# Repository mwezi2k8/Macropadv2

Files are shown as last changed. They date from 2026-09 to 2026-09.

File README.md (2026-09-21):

# 12-key macropad 

#what is it?
this is a custom 12-key mechanical macropad i designed in kicad from scratch. it runs on a seeed studio xiao rp2040 board instead of a bulky standard dev board, which keeps the whole thing compact and cheap. it has a 4x3 switch matrix with anti-ghosting diodes, a clickable rotary encoder knob, and a 4-pin header on top for a small i2c oled display.



# why make this?
i use a 60% keyboard daily, and while it looks clean and saves desk space, losing dedicated arrow keys, media buttons, and numpad shortcuts is honestly a pain. memorizing three-key layer combos while working or gaming gets frustrating fast. 

i wanted a standalone pad with dedicated hardware buttons for stuff like discord mutes, copy-pasting, app switching, and terminal shortcuts. plus, having a physical rotary dial to control volume or scrub timelines is way more satisfying than pressing function keys.



#how does it work?
- the key matrix:* the 12 switches are wired in a 4-column by 3-row grid connected directly to the xiao gpio pins. the micro-controller quickly scans through the rows and columns to check if a circuit is closed
- diodes* each switch has its own 1n4148 diode wired in series[cite: 3]. this stops back-powering across rows so you can press multiple keys at the same time without triggering phantom ghost clicks.
- rotary encoder:* the ec11 encoder pulses signals across two data pins whenever you turn it, letting the code figure out both direction and speed for scrolling or volume adjustments. the center shaft also clicks straight down, working as a 13th input switch
- oled screen:* hooked up to 5v, ground, sda, and scl pins. it talks over the i2c bus to show what profile or layer you are on, or display real-time stats like click counters.



#hardware & pcb specs
- controller:* seeed studio xiao rp2040
- keys:* 12 push switches arranged with standard 19.05 mm (1u) spacing so normal mechanical keycaps fit properly
- diodes:* 12x 1n4148 through-hole diodes placed next to each switch
- encoder:* ec11 rotary encoder with integrated push switch
- display connector:* 4-pin 2.54mm header for 0.96" i2c oled
- board size:*85.91 mm x 84.00 mm (2-layer pcb)



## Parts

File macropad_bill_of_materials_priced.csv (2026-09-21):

Item | Reference | Quantity | Component / Value | Footprint | Description | Unit Price (USD) | Total Price (USD)
1 | SW1 - SW12 | 12 | Cherry MX Compatible Switch | Button_Switch_Keyboard:SW_Cherry_MX_1.00u_PCB | Mechanical keyboard switch (Gateron / Outemu / Cherry) | 0.25 | 3.0
2 | D1 - D12 | 12 | 1N4148 Diode | Diode_THT:D_DO-35_SOD27_P7.62mm_Horizontal | High-speed switching diode (DO-35) | 0.03 | 0.36
3 | SW13 (SCROLL1) | 1 | EC11 Rotary Encoder | Rotary_Encoder:RotaryEncoder_Alps_EC11E-Switch_Vertical_H20mm | Rotary encoder with integrated push switch | 1.1 | 1.1
4 | U1 | 1 | Seeed Studio XIAO RP2040 | Seeed_XIAO:Seeed-XIAO / DIP-14_W15.24mm | Dual-core ARM Cortex-M0+ MCU module | 5.4 | 5.4
5 | J1 | 1 | Conn_01x04_Pin | Connector_PinHeader_2.54mm:PinHeader_1x04_P2.54mm_Vertical | 1x4 pin male header, 2.54mm pitch | 0.15 | 0.15
6 | DISP1 (External) | 1 | 0.96" I2C OLED Display | PinHeader_1x04_P2.54mm (Header) | 128x64 SSD1306 monochrome OLED module | 2.5 | 2.5
7 | PCB | 1 | Custom 2-Layer PCB | 85.91mm x 84.00mm | FR-4 2-Layer custom board (est. per board from 5-pack) | 1.5 | 1.5
8 | MISC1 | 12 | 1u Keycaps | Standard MX Stem | Standard 1u profile keycaps | 0.2 | 2.4
9 | MISC2 | 1 | Rotary Encoder Knob | 6mm Shaft | Aluminum / plastic knob cap for 6mm shaft | 0.75 | 0.75

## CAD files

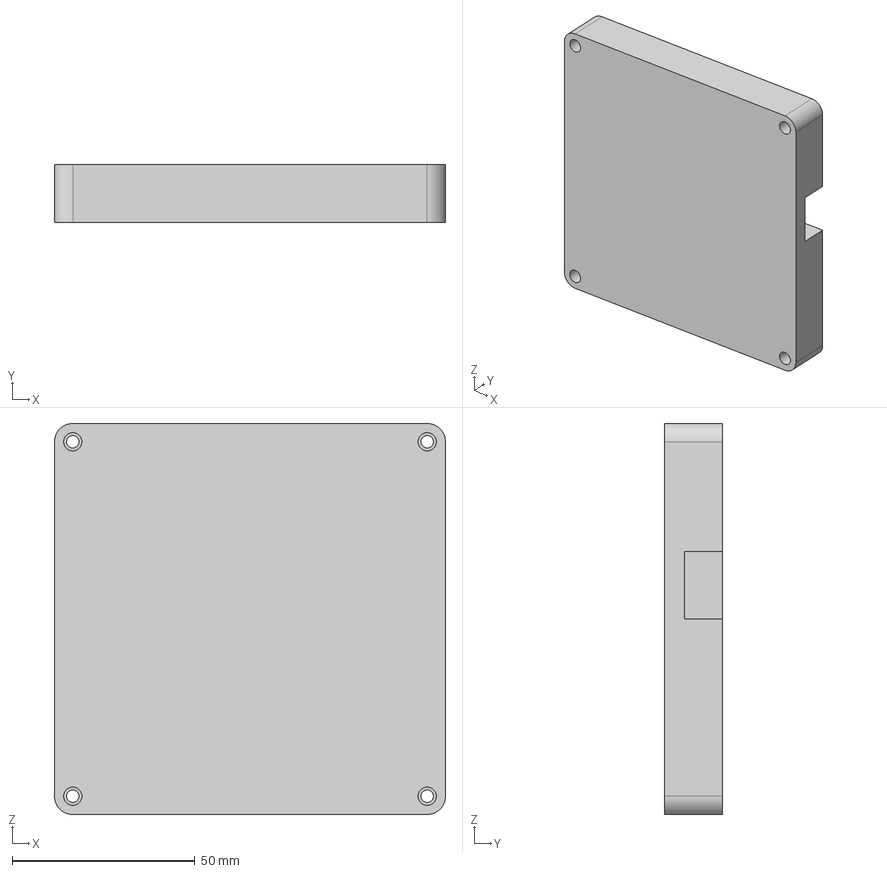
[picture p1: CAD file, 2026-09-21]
Case Bottom.step
106.9 x 15.9 x 106.9 mm

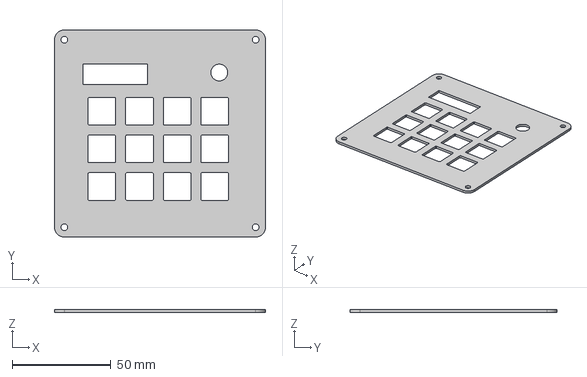
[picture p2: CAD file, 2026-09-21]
Case top.step
106.9 x 105.0 x 1.50 mm

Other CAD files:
Final Assembly Macropad.f3z

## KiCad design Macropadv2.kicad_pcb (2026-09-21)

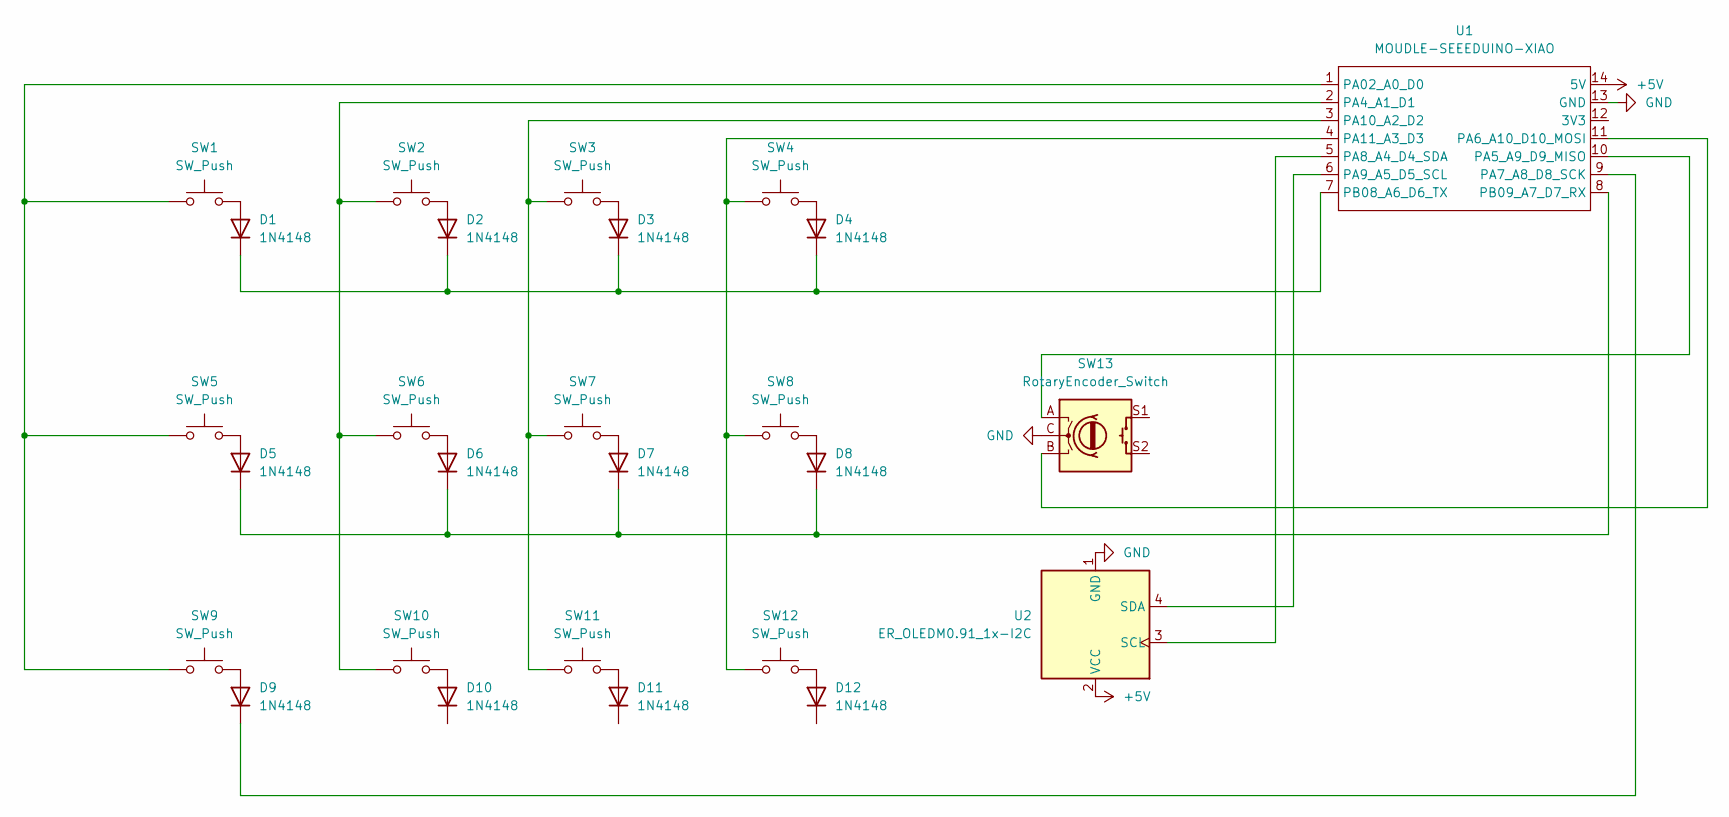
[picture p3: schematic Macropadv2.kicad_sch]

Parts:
D1, D2, D3, D4, D5, D6, D7, D8, D9, D10, D11, D12: 1N4148; D_DO-35_SOD27_P7.62mm_Horizontal
SW1, SW2, SW3, SW4, SW5, SW6, SW7, SW8, SW9, SW10, SW11, SW12: SW_Push; SW_NKK_GW12LJP
SW13: RotaryEncoder_Switch; RotaryEncoder_Alps_EC11E-Switch_Vertical_H20mm
U1: MOUDLE-SEEEDUINO-XIAO; XIAO-Generic-Hybrid-14P-2.54-21X17.8MM
U2: ER_OLEDM0.91_1x-I2C

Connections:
+5V: U1.14 (5V), U2.2 (VCC)
GND: SW13.C, U1.13 (GND), U2.1 (GND)
unnamed: D1.2 (A), SW1.2
unnamed: D1.1 (K), D2.1 (K), D3.1 (K), D4.1 (K), U1.7 (PB08_A6_D6_TX)
unnamed: D2.2 (A), SW2.2
unnamed: D3.2 (A), SW3.2
unnamed: D4.2 (A), SW4.2
unnamed: D5.2 (A), SW5.2
unnamed: D5.1 (K), D6.1 (K), D7.1 (K), D8.1 (K), U1.8 (PB09_A7_D7_RX)
unnamed: D6.2 (A), SW6.2
unnamed: D7.2 (A), SW7.2
unnamed: D8.2 (A), SW8.2
unnamed: D9.2 (A), SW9.2
unnamed: D9.1 (K), U1.9 (PA7_A8_D8_SCK)
unnamed: D10.2 (A_2), SW10.2
unnamed: D11.2 (A_2), SW11.2
unnamed: D12.2 (A_2), SW12.2
unnamed: SW1.1, SW5.1, SW9.1, U1.1 (PA02_A0_D0)
unnamed: SW2.1, SW6.1, SW10.1, U1.2 (PA4_A1_D1)
unnamed: SW13.A, U1.10 (PA5_A9_D9_MISO)
unnamed: SW13.B, U1.11 (PA6_A10_D10_MOSI)
unnamed: U1.5 (PA8_A4_D4_SDA), U2.3 (SCL)
unnamed: U1.6 (PA9_A5_D5_SCL), U2.4 (SDA)
unnamed: SW3.1, SW7.1, SW11.1, U1.3 (PA10_A2_D2)
unnamed: SW4.1, SW8.1, SW12.1, U1.4 (PA11_A3_D3)

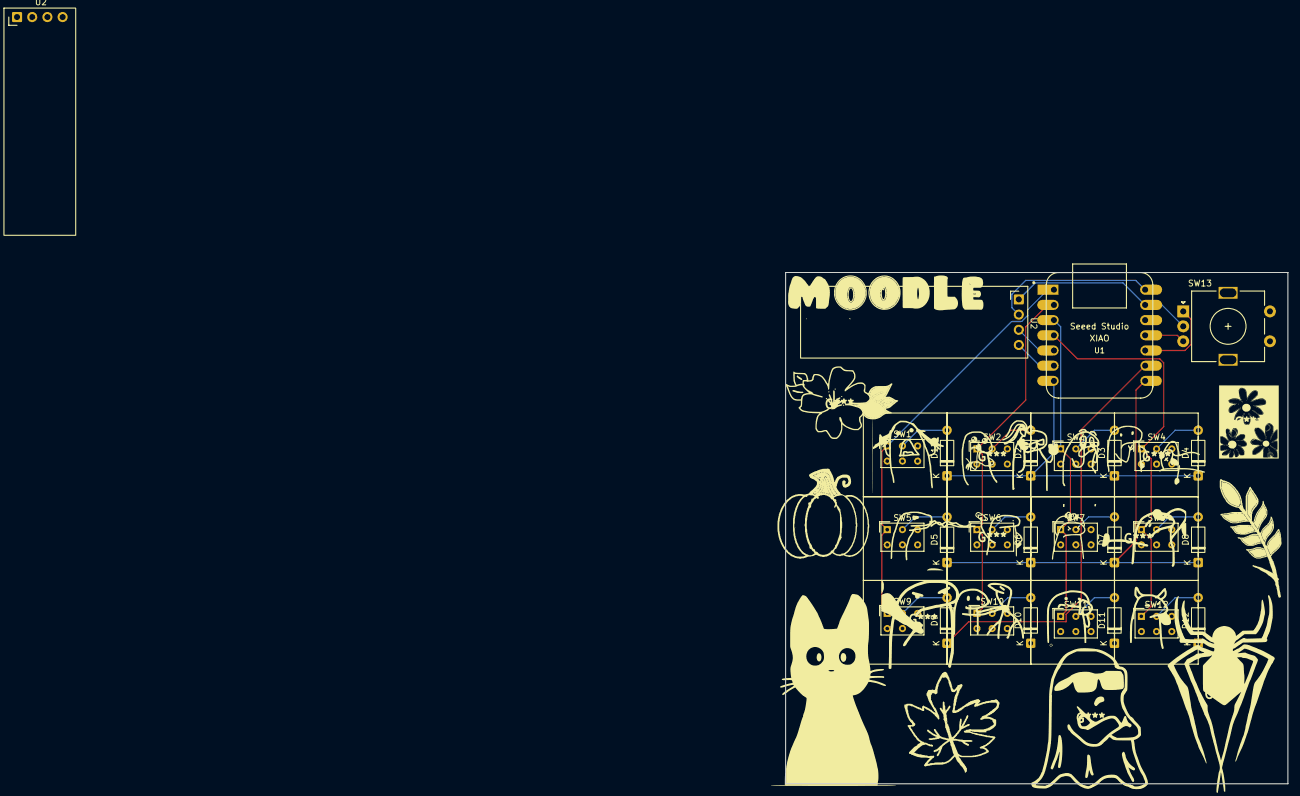
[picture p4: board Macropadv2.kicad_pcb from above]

Board: 2 copper layers, 84.0 x 85.5 mm, 28 parts (0 on the bottom side), 25 nets.

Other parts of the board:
U2#2: ER_OLEDM0.91_1x-I2C

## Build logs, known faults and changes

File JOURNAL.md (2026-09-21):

Journal #1 : Making the Case!
by@aryansalvehub

Total Time Spent : 2Hrs 32min

By@aryansalvehub

Starting the project, the plan was to make the case! For this hackpad, I am designing the case in two part, 1st part is to make upper body of the case and the other was to make the bottom of the case, the bottom case was a box with hollow space for the PCB and the space for USB connection of hackpad to the device. 


For the 2nd Part I made a simple plate with gap for the keys the OLED panel and for the rotating dial too. The design was too added in the 2nd part and Extended to part 1 an idea to add some more hand holding design with more than a box like some thing different from just box.


Journal #2
by @Mwezi2000
Total time - 1 hr 10 min 

I started by placing the Seeeduino XIAO (U1) on the right side of the sheet. I put the 12 switches (SW1–SW12) in a 3×4 grid on the left, each with its own 1N4148 diode (D1–D12).
I wired the keys as a matrix instead of giving every key its own pin. A matrix uses far fewer GPIOs, and the XIAO doesn't have many. The wiring works like this:
* Each of the 4 columns is a vertical wire connecting the left side of the 3 switches in that column. Those wires go to XIAO pins D0–D3.
* Each of the 3 rows is a horizontal wire connecting the diode cathodes across that row, and it goes to its own pin on the XIAO.
* Every switch has a diode in series, so pressing several keys at once doesn't cause ghosting.
Next I added the rotary encoder (SW13). Its A and B pins go to two GPIO pins, the common pin C goes to GND, and I labelled the GND connection with a power symbol.
Last I added J1, a 4-pin header with GND, +5V, and two signal lines going to the XIAO's SDA and SCL pins. This lets me plug in an I2C device such as an OLED display. I also connected the XIAO's 5V and GND pins to the +5V and GND power symbols.
￼

Final schematics - 
	•	U1 — MOUDLE-SEEEDUINO-XIAO (14-pin module)
* 12x SW_Push (SW1-SW12) in a 3-row x 4-column matrix, each with a 1N4148 diode
* SW13 — RotaryEncoder_Switch (SCROLL1), wired to A/B/GND/S1/S2
* J1 — Conn_01x04_Pin, breaking out GND / +5V / OLED_SDA / OLED_SCL for the OLED panel
* Row1-3 and Col1-4 nets routed across the matrix; SDA/SCL shared between the OLED connector and controller

Journal #3 by @aryansalve041
Total Time - 2hrs 32 min(case modification) + 3 hrs (art design)

I felt something off at the case deign and some structural errors so i gave some of my time to fix the structurals errors and the other thing was make it more live,
so i added some wavy feels rather than keepig it like simple box and i too added some of boundary for rotatory switch so that themiddle part which was first visibble to viewwer now could hide so that it would feel kind of stylish rather keeping it like a mechanical feels. I too removed unneccasary part space taking to fit the PCB more precisely. i also added the boundary to the OLED  Screen so that the side part is less visible and the screens feels more wide.


Now moving toward some styling part of case and PCB sso that it would feel more real and could see it as a mark.
This was my first time using Krita, so I spent some time getting familiar with the different tools and the interface. I started by trying out the brush, eraser, colours, layers and basic shapes. I then started making the artwork for my on-board design. Since I was using a mouse, making smooth lines and small details was a bit difficult, and I had to use undo and eraser quite often. I also experimented with different brush sizes and layers to make the design look better.
In the last part, I cleaned up the unwanted lines, adjusted some details and made a few changes to the colours and overall look. Overall, it took me around 2.5–3 hours, and I got more comfortable with Krita while making the artwork.



journal #4
By @Mwezi2000

Total time - 1hr 46 mins (pcb editor part 1) + 51 mins (art) + 3hrs 41 mins ( art again ) = 6hrs 18 mins

so after completing my schematics for pcb I wen off to the kicad pcb editor
It was my first time using it, which was really fun! (I got stuck at making that grid for keys and did it manually at last-)
I also did some changes on the pcb scheme, checked all the footprints then imported on pcb editor
Then it was just arranging these components on their places which looked very congested at first
But at last I was sure it would turn out really beautiful !
I was bored of pcb editor so I started making some art for my pcb 


￼

Again this was my first time using krita (didnt expect it would go so well)
I started making all the things I could think of also I tried to keep it related to our theme Harvest!

 

￼

So the first one was trial but I decided to keep it, the next two turned out to be good 
I went for a break then but came back to draw some of my coolest stickersssss (still can’t believe, krita was so fun!)

 

￼

This took me a whole bunch of time but turned out real beauty
I loved it so much that I just forgot about the pcb, and went on drawing! Every cool thing I could think of, I seriously couldn’t stop myself 
I thought to write out team logo and then I also made our friendly neighbour spidermans logo!

￼



Finally back to completing the pcb!

Journal #5
By Mwezi2000

Time- 2hrs 2mins (finally completed the pcb and added all the art)
 
Since I couldn’t figure how to add the hole matrix for the keys, I did it all manually each rectangle! One by one, but I made it 
After that all it was left to connect the components, it went out pretty clean since I already arranged the parts neatly 



￼
The only thing left now was to add all the cool stickers I made before, and the pcb looks amazing after adding them!
Also my team mate @aryansalve041 himself made some really cool art for my pcb which I added in middle 





￼

￼

For its 3d printed case, this is the design we will be putting on the back of the case



journal #6
By Mwezi2000

Time- 23 mins

i finally updated my github reopo and uploaded all the pcb, BOM and readme files from my side

Journal #7
by@aryansalvehub

time - 2hrs 9 min

I have been working on my macropad’s firmware today. More precisely, I have been coding the 3×4 matrix keypad, rotary encoder, OLED display, and USB Human Interface Device in C++.

In particular, I have been working on the creation of the layers, namely Code, Media, Streaming, and Text, each of which is supposed to have different actions depending on the key pressed. Moreover, I have been adding various shortcuts, such as copy, paste, save, undo, media controls, and text-related shortcuts.

As I am relatively new to embedded programming, it took me a while to get familiar with the syntax, key identifiers, key macros, keyboard modifiers, and the way the rotary encoder and keys are read by microcontroller. Moreover, debugging some minor issues in code and syntax was also part of today’s work.

In general, today I have learned how to establish a connection between the input mechanism and the output actions or data in the context of a custom macro pad and learned about the basics of embedded programming.



￼

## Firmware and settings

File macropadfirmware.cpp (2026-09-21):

#include <Adafruit_TinyUSB.h>
#include <Wire.h>
#include <Adafruit.GFX.h>
#include <Adafruit.SSD1206.h>


const byte columns[4] = {D0, D1, D2, D3};
const byte rows[3] = {D6, D7, D8};

#define ENCODER_A D9 
#define ENCODER_B D10


#define DEBOUNCE_TIME 6
#define LONG_PRESS_TIME 600

#define SCREEN_WIDTH 128
#define SCREEN_HEIGHT 32

#define OLED_ADDRESS 0x3C

#define NUMBER_OF_LAYERS 4


enum {
    KEYBOARD_ID = 1;
    MEDIA_ID = 2;

};

unit8_t hidDescription[] = {
    TUD_HID_REPORT_DESC_KEYBOARD(HID_REPORT_ID(KEYBOARD_ID)),
    TUD_HID_REPORT_DESC_CONSUMER(HID_REPORT_ID(MEDIA_ID))
};

Adafrui_USBD_HID usbHID;

#define CTRL KEYBOARD_MODIFIER_LEFCTRL
#define SHIFT KEYBOARD_MODIFIER_LEFTSHIFT
#define ALT KEYBOARD_MODIFIER_LEFTALT


enum ActionType {
    NOTHING,
    KEY,
    MEDIA,
    TEXT,
    LAYER

};


struct ButtonAction {
    ActionType type;
    byte modifier;
    unit16_t key;
    const char *text;
    const char *name;

    
};

#define KEY_ACTION(name, key) \
{KEY, 0, key, nullptr, name}

#define MOD_ACTION (name, mod, key)  \
{KEY, mod, key, nullptr, name}

#define MEDIA_ACTION (name, txt) \
{KEY, 0, key, nullptr, name}

#define TEXT_ACTION (name, txt) \
{TEXT, 0, 0, txt, name}

#define LAYER_ACTION \
{LAYER, 0, 0, nullptr, "LAYER"}

#define EMPTY_ACTION \
{NOTHING, 0, 0, nullptr, ""}


struct Layer {
    const char *name;

    ButtonAction buttons[12];

    ButtonAction encoderCW;
    ButtonAction encoderCCW;

};


const Layer layers[NUMBER_OF_LAYERS] = {
    
    {
        "CODE",

    {
        MOD_ACTION("COPY", CTRL, HID_KEY_C),
        MOD_ACTION("PASTE", CTRL, HID_KEY_V),
        MOD_ACTION("UNDO", CTRL, HID_KEY_Z),
        MOD_ACTION("REDO", CTRL, HID_KEY_Y),

        MOD_ACTION("SAVE", CTRL, HID_KEY_S),
        MOD_ACTION("FIND", CTRL, HID_KEY_F),
        MOD_ACTION("COMMENT", CTRL,HID_KEY_SLASH),
        KEY_ACTION("RUN", CTRL, HID_KEY_F5),

        MOD_ACTION("TERM", CTRL, HID_KEY_GRAVE),
        MOD_ACTION("OPEN", CTRL, HID_KEY_P),
        MOD_ACTION("CMD", CTRL | SHIFT, HID_KEY_P),
        LAYER_ACTION

    },

    MOD_ACTION("TAB >", CTRL, HID_KEY_TAB),
    MOD_ACTION("<TAB", CTRL | SHIFT, HID_KEY_TAB)
},

{ 
    MEDIA_ACTION("PREV", HID_USAGE_CONSUMER_SCAN_PREVIOUS),
    MEDIA_ACTION("PLAY", HID_USAGE_CONSUMER_PLAY_PAUSE),
    MEDIA_ACTION("NEXT", HID_USAGE_CONSUMER_SCAN_NEXT),
    MEDIA_ACTION("MUTE", HID_USAGE_CONSUMER_MUTE),

    MEDIA_ACTION("VOL -", HID_USAGE_CONSUMER_VOLUME_DECREMENT),
    MEDIA_ACTION("VOL +", HID_USAGE_CONSUMER_VOLUME_INCREMENT),
    MEDIA_ACTION("STOP", HID_USAGE_CONSUMER_STOP),
    EMPTY_ACTION,

    MEDIA_ACTION("BRIGHT -", HID_USAGE_CONSUMER_BRIGHTNESS_DECREMENT),
    MEDIA_ACTION("BRIGHT +", HID_USAGE_CONSUMER_BRIGHTNESS_INCREMENT),
    EMPTY_ACTION,
    LAYER_ACTION,

}

  MEDIA_ACTION("VOL +", HID_USAGE_CONSUMER_VOLUME_INCREMENT),
  MEDIA_ACTION("VOL -", HID_USAGE_CONSUMER_VOLUME_DECREMENT),

},


{
    "STRM",

    {
        KEY_ACTION("SCENE 1", HID_KEY_F13),
        KEY_ACTION("SCENE 2", HID_KEY_F14),
        KEY_ACTION("SCENE 3", HID_KEY_F15),
        KEY_ACTION("SCENE 4", HID_KEY_F16),

        KEY_ACTION("MIC", HID_KEY_F17),
        KEY_ACTION("DEAFEN", HID_KEY_F18),
        KEY_ACTION("REC", HID_KEY_F19),
        KEY_ACTION("LIVE", HID_KEY_F23),
        LAYER_ACTION


    },

    KEY_ACTION("MIC +", HID_KEY_F24),
    MOD_ACTION("MIC-", ALT, HID_KEY_F24)

},


{
    TEXT_ACTION("HELLO", "hello!"),
    TEXT_ACTION("THANKS", "thanks will check it out"),
    TEXT_ACTION("GG", "gg wp"),
    TEXT_ACTION("EMAIL", "you@example.com"),

    TEXT_ACTION("STATUS", "git status\n"),
    TEXT_ACTION("PULL", "git pull\n"),
    TEXT_ACTION("DEV", "npm run dev\n"),
    TEXT_ACTION("LS", "ls -la\n"),

    TEXT_ACTION("LOL", "lol"),
    TEXT_ACTION("BRB", "brb"),
    TEXT_ACTION("PATH", "~/projects/"),
    LAYER_ACTION

},

    KEY_ACTION("DOWN", HID_KEY_ARROW_DOWN),
    KEY_ACTION("UP", HID_KEY_ARROW_UP),
}

};

Adafruit_SSD1306 display(
    SCREEN_WIDTH,
    SCREEN_HEIGHT,
    &Wire,
    -1

);

bool displayWorking = false;

int currentLayer = 0;


const ButtonAction *heldButtons[12] = {nullptr};

unsigned long layerButtonTime = 0;


struct ButtonState {
    bool rawState;
    bool stableState;
    unsigned long lastChange;

};

ButtonState buttond[12];

volatile int encoderChange = 0;
volatile byte encoderState = 0;

const int8_t encoderTable[12] = {
    0, -1, 1, 0,
    1, 0, 0, -1,
    -1, 0, 0, 1,
    0, 1, -1, 0

};

unsigned long lastScreenUpdate = 0;
unsigned long lastInput = 0;

unsigned long messageEnd = 0;
unsigned long layerPopupEnd = 0;

unsigned long animationFrame = 0;

bool displayedDimmed = false;
bool displayOff = false;

chr currenMessage[14] = "";

void sendKeyboard(byte modifier, byte key) {

    if (!TinyUSBDevice.mounte())
    return;

    for (int i = 0; i < 20; i++) {

        if (usbHID.ready())
        break;

        delay(1);

}

byte keys[6] = {
    key, 0, 0, 0, 0, 0

};

usbHID.keyboardReport(
    KEYBOARD_ID,
    modifier,
    keys

);

}


void releaseKeyboard() {
    
    if (TinyUSBDevice.mounted())
    return;

    byte keys[6] = {0};


    usbHID.keyboardReport(
        KEYBOARD_ID,
        0,
        keys
    );

}


void sendMedia(unit16_t code) {

    if (!TinyUSBDevice.mounted())
    return;

    for (int i 0; i < 20; i++) {
        
        if (usbHID.ready())
        break;

        delay(1);

    }

    usbHID.sendReport16(
        MEDIA_ID,
        code
    
    );

}


void dupdateHeldKeys () {

    byte modifier = 0;

    byte keys[6] = {0};

    int numberOfKeys = 0;

    for (int = 0; i < 12; i++) {

        if (heldButtons[i] == nullptr)
        continue;

        if (heldButtons[i]->type != KEY)
        continue;

        modifier |= heldButtons[i]->modifier;

        if (numberOfKeys < 6) {

            keys [numberOfKeys] = 
            heldButtons[i]->key;

            numberOfKeys++;

        
        }

}

if (!TinyUSBDevice.mounted())
return;

usbHID.keyboardReport(
    KEYBOARD_ID,
    modifier,
    keys


);

}


void releaseEverything() {

    for (int i = 0; i < 12; i++) {
        
        heldButtons[i] = nullptr;

    }

    updateHeldKeys();

    sendMedia(0);

}
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

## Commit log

2026-09-20 Add detailed journal entry for Seeeduino XIAO project
    Documented the setup and wiring of the Seeeduino XIAO with switches and rotary encoder.
2026-09-20 Update JOURNAL.md with project journal entries
    Added journal entries detailing project progress and design elements for the case and components.
2026-09-21 Update JOURNAL with PCB and art progress
    Documented progress on PCB design and art creation, including time spent and tools used.
2026-09-21 Update JOURNAL.md with PCB project details
    Documented the completion of the PCB project, including manual key matrix creation and addition of art and stickers.
2026-09-21 Create PCB
